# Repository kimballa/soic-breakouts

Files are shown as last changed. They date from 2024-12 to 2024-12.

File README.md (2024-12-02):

SOIC Breakouts
==============

Breakout boards for {8, 14, 16}-pin SOIC and TSSOP ICs
that fit in a standard DIP width on a breadboard.

The IC itself sits to the side of the pin headers rather than between them, to achieve a
narrow breakout board profile (10.3mm) that does not straddle an extra row of pins on one
or the other side of the breadboard centerline. 

A separate through-hole exists in each SOIC board, connected to the ground plane. Solder a
resistor leg or other thin wire from the `GND` hole to top of the header pin that
represents ground for the IC. (Or leave floating if there is no appropriate ground pin for
the IC.)

## Gerber files

The latest gerber files for submitting to a board fab are in the `rtm/` directory.

If submitting to JLCPCB, select 'panel by customer', 'number of designs' = 3. 

## Panelization

The main project file includes one of each representative breakout board. Panels with 8 of
each SOIC or 8 of each TSSOP format were generated using KiKit. If you change the main PCB
CAD file, you should then open a KiCad Command Prompt in this directory and run `python
panelize.py`. You can edit `panelize.py` first to set variables related to the output file
to generate. You need to edit the script to select B1-B3 (SOIC), or B4-B6 (TSSOP boards)
for panelization.

### Script notes:

The current layout (n=8) is intended to fit in the 100x100 mm area that offers the best
deal for JLCPCB, but you can extend wider. The script would need to be modified to include
more than one row of each board. The script also assumes that all boards are the same
width, and may misalign columns if not accounted-for in any future modification that
changes some of the board widths.

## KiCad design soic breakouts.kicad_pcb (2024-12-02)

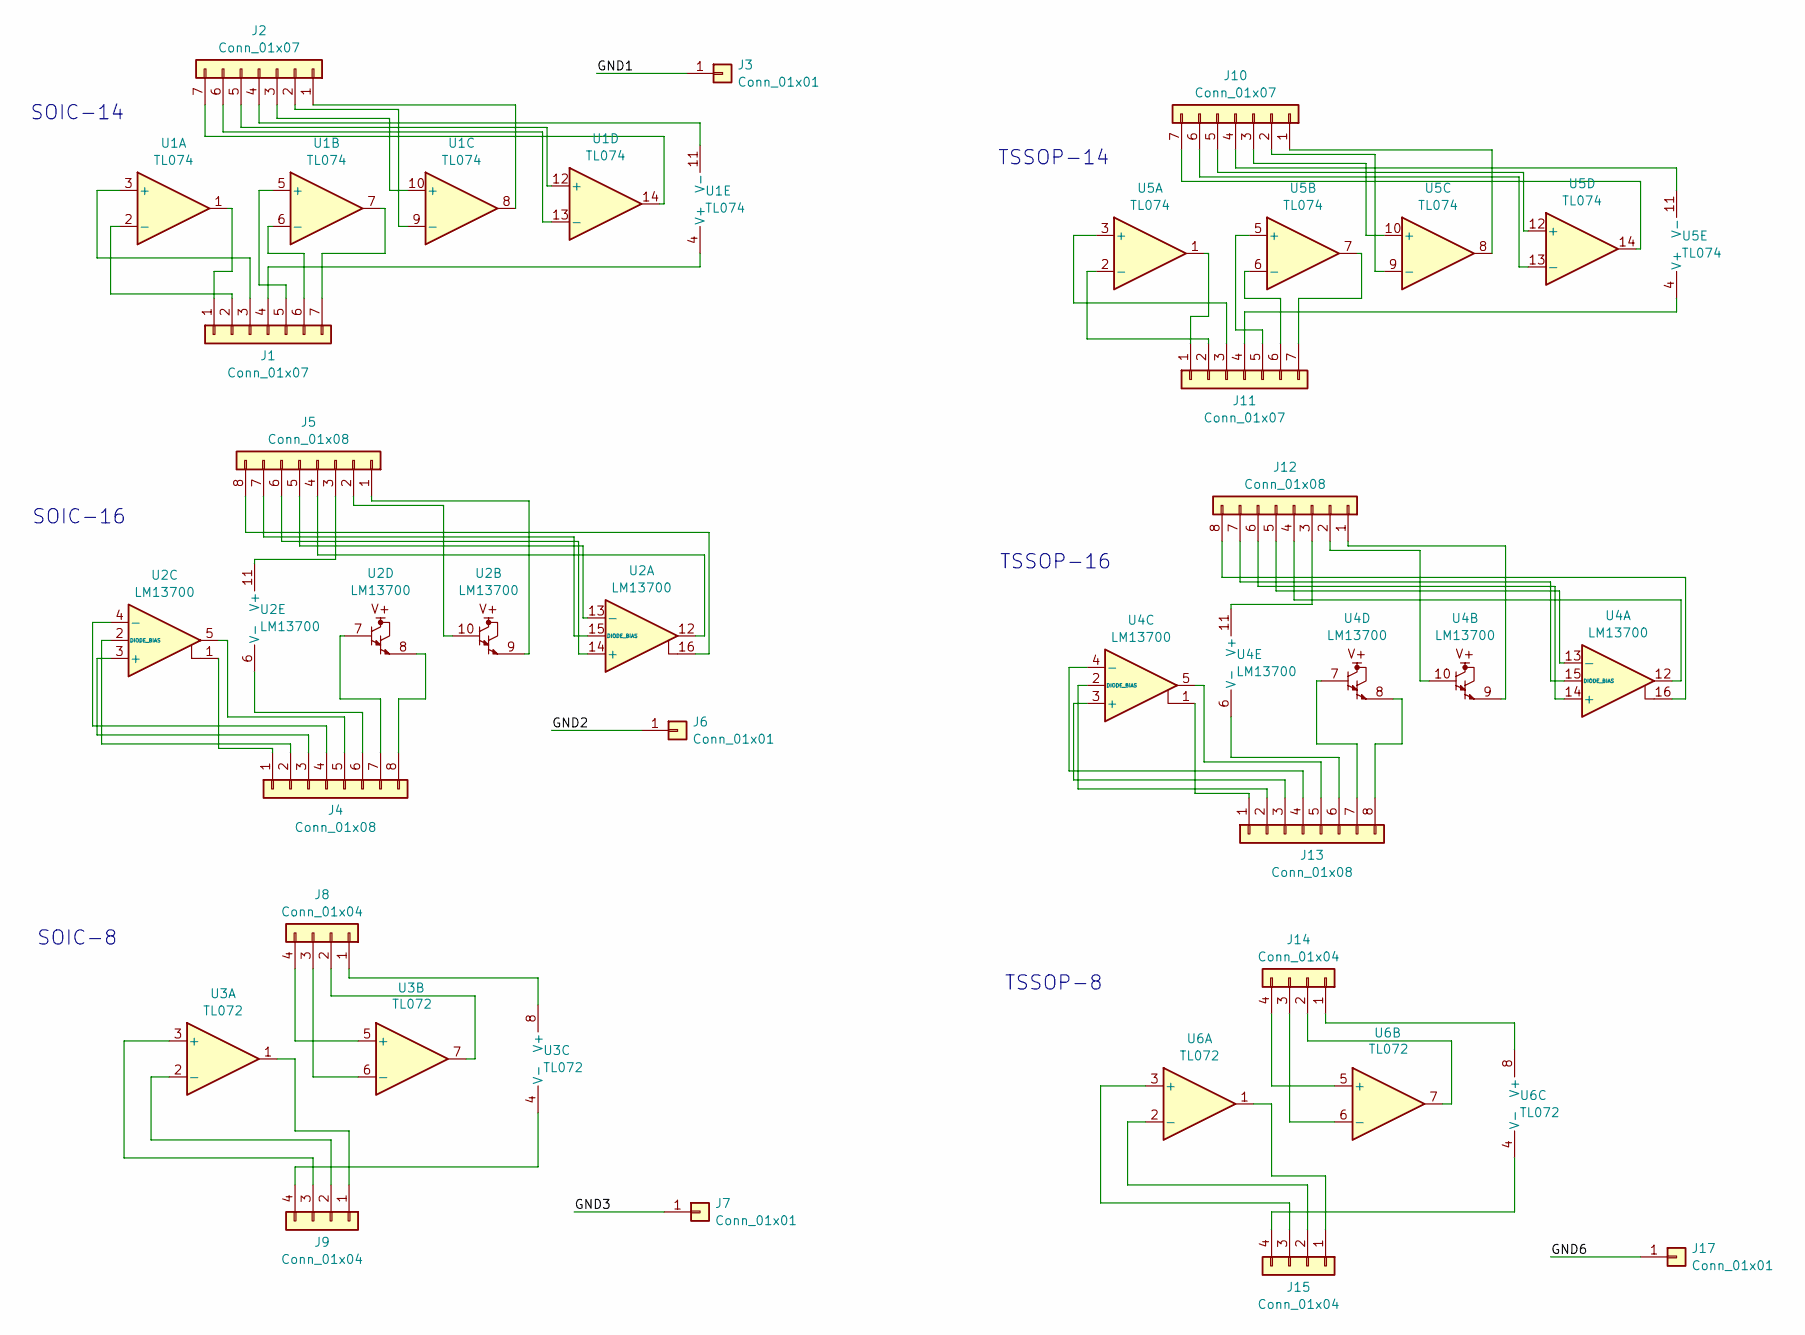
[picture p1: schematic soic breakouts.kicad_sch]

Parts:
J1, J2, J10, J11: Conn_01x07; PinHeader_1x07_P2.54mm_Vertical
J3, J6, J7, J17: Conn_01x01; TP_HeaderPin_P2.54mm_round
J4, J5, J12, J13: Conn_01x08; PinHeader_1x08_P2.54mm_Vertical
J8, J9, J14, J15: Conn_01x04; PinHeader_1x04_P2.54mm_Vertical
U1: TL074; TI_SOIC_D_R-PDSO-G14
U2: LM13700; TI_SOIC_D_R-PDSO-16
U3: TL072; TI_SOIC_D_R-PDSO-8
U4: LM13700; TSSOP-16_4.4x5mm_P0.65mm
U5: TL074; TI_TSSOP_PW0014A
U6: TL072; TI_TSSOP_PW0008A

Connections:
/GND1: J3.1
/GND2: J6.1
/GND3: J7.1
/GND6: J17.1
unnamed: J1.1, U1.1
unnamed: J1.2, U1.2 (-)
unnamed: J1.3, U1.3 (+)
unnamed: J1.4, U1.4 (V+)
unnamed: J1.5, U1.5 (+)
unnamed: J1.6, U1.6 (-)
unnamed: J1.7, U1.7
unnamed: J2.1, U1.8
unnamed: J2.2, U1.9 (-)
unnamed: J2.3, U1.10 (+)
unnamed: J2.4, U1.11 (V-)
unnamed: J2.5, U1.12 (+)
unnamed: J2.6, U1.13 (-)
unnamed: J2.7, U1.14
unnamed: J4.1, U2.1
unnamed: J4.2, U2.2 (DIODE_BIAS)
unnamed: J4.3, U2.3 (+)
unnamed: J4.4, U2.4 (-)
unnamed: J4.5, U2.5
unnamed: J4.6, U2.6 (V-)
unnamed: J4.7, U2.7
unnamed: J4.8, U2.8
unnamed: J5.1, U2.9
unnamed: J5.2, U2.10
unnamed: J5.3, U2.11 (V+)
unnamed: J5.4, U2.12
unnamed: J5.5, U2.13 (-)
unnamed: J5.6, U2.14 (+)
unnamed: J5.7, U2.15 (DIODE_BIAS)
unnamed: J5.8, U2.16
unnamed: J8.1, U3.8 (V+)
unnamed: J8.2, U3.7
unnamed: J8.3, U3.6 (-)
unnamed: J8.4, U3.5 (+)
unnamed: J9.1, U3.1
unnamed: J9.2, U3.2 (-)
unnamed: J9.3, U3.3 (+)
unnamed: J9.4, U3.4 (V-)
unnamed: J10.1, U5.8
unnamed: J10.2, U5.9 (-)
unnamed: J10.3, U5.10 (+)
unnamed: J10.4, U5.11 (V-)
unnamed: J10.5, U5.12 (+)
unnamed: J10.6, U5.13 (-)
unnamed: J10.7, U5.14
unnamed: J11.1, U5.1
unnamed: J11.2, U5.2 (-)
unnamed: J11.3, U5.3 (+)
unnamed: J11.4, U5.4 (V+)
unnamed: J11.5, U5.5 (+)
unnamed: J11.6, U5.6 (-)
unnamed: J11.7, U5.7
unnamed: J12.1, U4.9
unnamed: J12.2, U4.10
unnamed: J12.3, U4.11 (V+)
unnamed: J12.4, U4.12
unnamed: J12.5, U4.13 (-)
unnamed: J12.6, U4.14 (+)
unnamed: J12.7, U4.15 (DIODE_BIAS)
unnamed: J12.8, U4.16
unnamed: J13.1, U4.1
unnamed: J13.2, U4.2 (DIODE_BIAS)
unnamed: J13.3, U4.3 (+)
unnamed: J13.4, U4.4 (-)
unnamed: J13.5, U4.5
unnamed: J13.6, U4.6 (V-)
unnamed: J13.7, U4.7
unnamed: J13.8, U4.8
unnamed: J14.1, U6.8 (V+)
unnamed: J14.2, U6.7
unnamed: J14.3, U6.6 (-)
unnamed: J14.4, U6.5 (+)
unnamed: J15.1, U6.1
unnamed: J15.2, U6.2 (-)
unnamed: J15.3, U6.3 (+)
unnamed: J15.4, U6.4 (V-)

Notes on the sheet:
SOIC-14
TSSOP-8
SOIC-8
TSSOP-14
SOIC-16
TSSOP-16

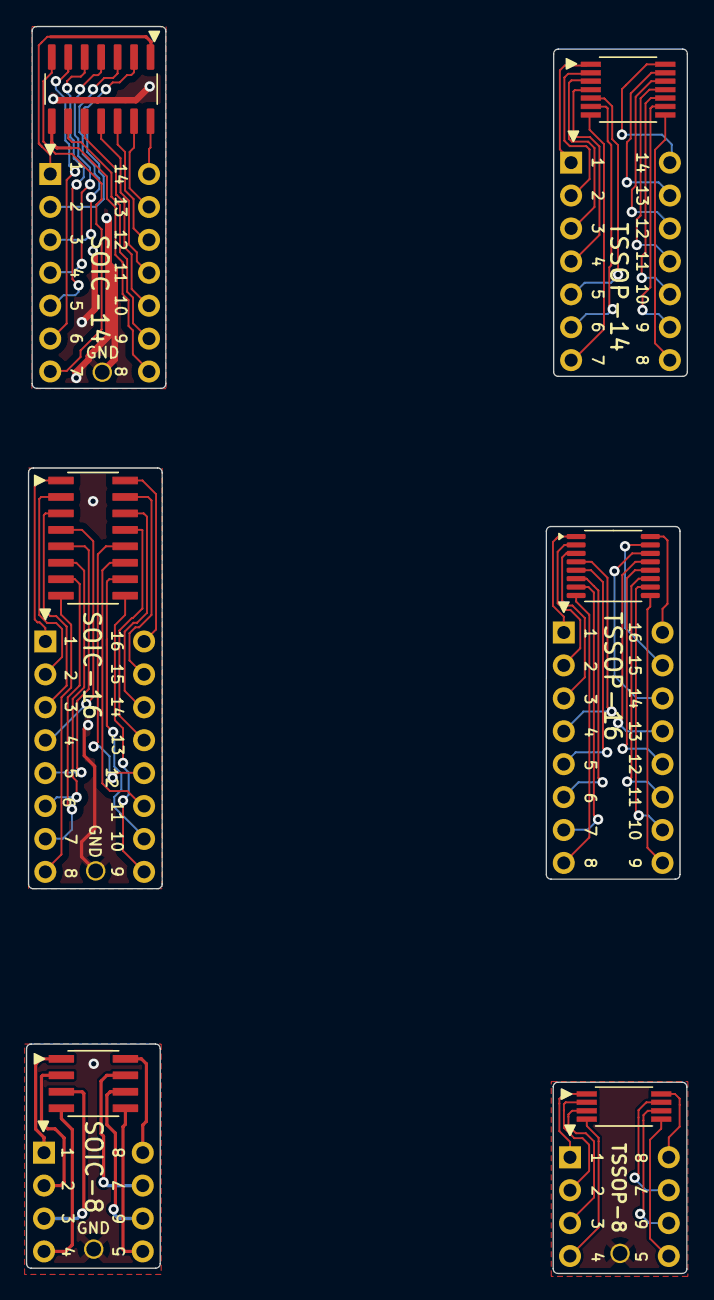
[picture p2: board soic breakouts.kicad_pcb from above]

Board: 2 copper layers, 51.0 x 96.2 mm, 28 parts (0 on the bottom side), 76 nets.

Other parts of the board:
B1, B2, B3, B4, B5, B6: Board

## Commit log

2023-12-29 Add project files.
    [soic breakouts.kicad_pcb, soic breakouts.kicad_sch]
2023-12-29 Some schema edits.
    [soic breakouts.kicad_sch]
2023-12-29 Add v1.0 RTM gerbers.
    [soic breakouts-B_Cu.gbl, soic breakouts-B_Mask.gbs, soic breakouts-B_Paste.gbp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]
2024-12-01 Add SOIC-8.
    * Update to KiCAD 8 format.
    * Add SOIC-8 footprint breakout.
    * Update to new IPC pin 1 (triangle/arrow) indicator throughout.
    * Make pin 1 on header more obvious with IPC indicator throughout.
    * Increase silkscreen font size for main label per breakout board.
    [soic breakouts.kicad_pcb, soic breakouts.kicad_sch]
2024-12-01 Add TSSOP-8, -14, -16 breakouts.
    Now have SOIC and TSSOP for 8/14/16 pin variants.
    [soic breakouts.kicad_pcb, soic breakouts.kicad_sch]
2024-12-02 Add KiKit panelization script.
    Added python script using KiKit SDK to generate separate
    SOIC and TSSOP breakout board panels.
    [soic breakouts.kicad_pcb]
2024-12-02 Add v2.0 RTM gerbers for SOIC and TSSOP panels.
    [soic-B_Cu.gbl, soic-B_Mask.gbs, soic-B_Paste.gbp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]
